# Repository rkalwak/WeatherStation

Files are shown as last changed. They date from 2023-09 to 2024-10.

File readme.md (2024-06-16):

# Stacja pogodowa

Poczytałem trochę co będzie potrzebne, kupiłem niekompletna stacje Sainlogic WS3500 na A****** i tak powstało to cudo :D

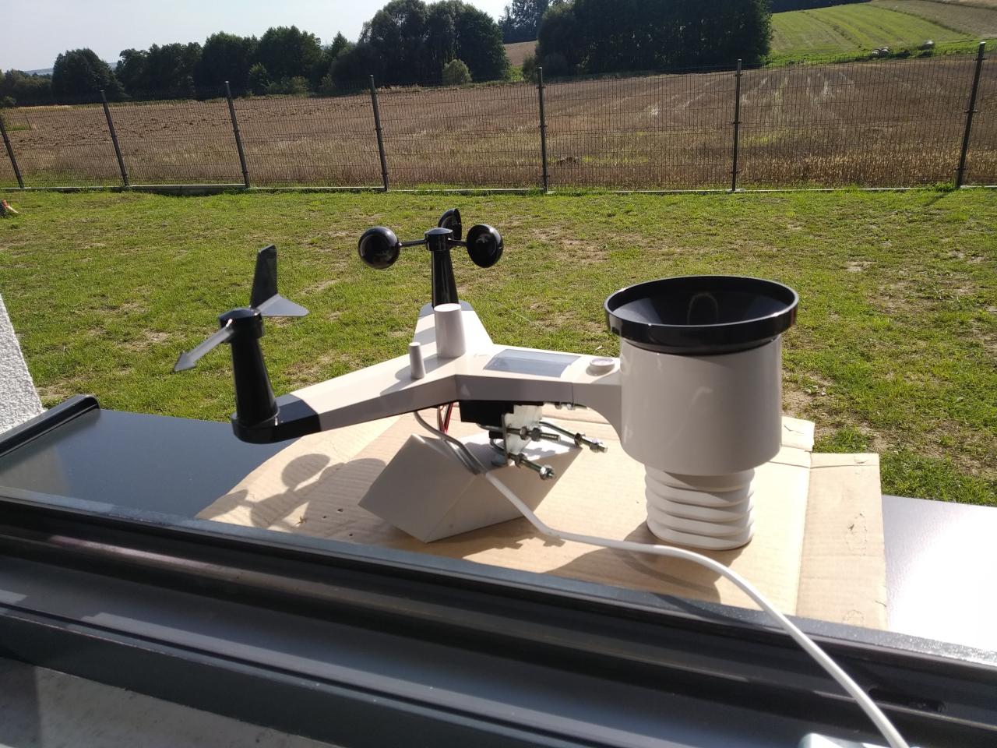
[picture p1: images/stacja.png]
stacja


## Funkcjonalności:
* 2x temperatura,
* wilgotność,
* ciśnienie atmosferyczne,
* siła i kierunek wiatru,
* ilość opadów,
* pył PM_0.5
* pył PM_1.0
* pył PM_2.5
* pył PM_4.0
* pył PM_10.0

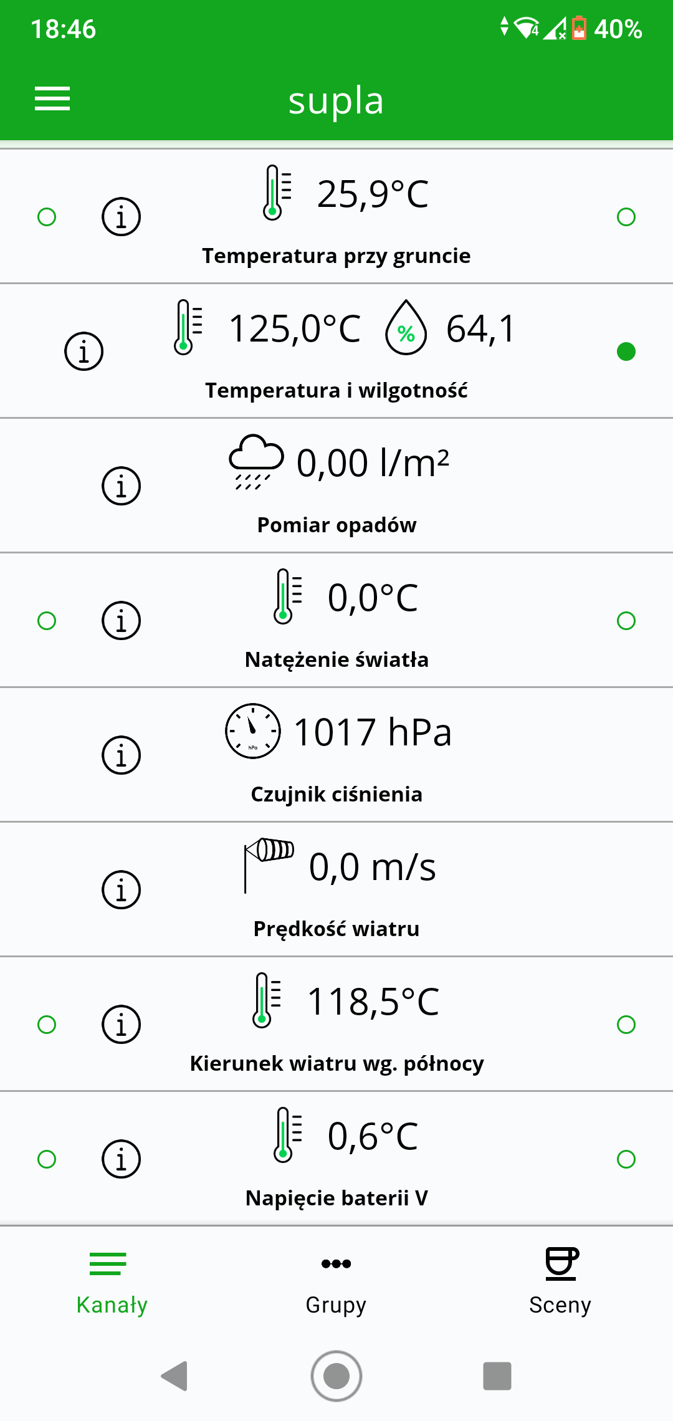
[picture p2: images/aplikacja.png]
aplikacja


## Części:
* niekompletna stacja Sainlogic WS3500 - bez tabletu i zasilacza -> nie można jej skonfigurować, ale nieuszkodzona, wyrwana za 100zł :D
* ESP32 DevKit
* HDC1080 - czujnik wilgotności i temperatury
* MS5611 - czujnik ciśnienia
* DS18B20 - czujnik temperatury przy gruncie
* LTR390 - czujnik UV i natężenia światła wbudowany w stację, użyty jako ten drugi
* AS5600 - enkoder magnetyczny, zastąpił czujnik kierunku wiatru w stacji
* czujnik Halla - zastąpil czujnik siły wiatru w stacji , ten od czujnika opadów został
* 2 baterie 18650 LiPo i koszyk
* lx-lifc1-n - Moduł BMS z ładowarką do akumulatorów Li-ion 2S z USB typu C i obsługą QC, możliwość ładowania z USB albo panelu.
* przetwornica step-down
* panel fotowoltaiczny dający 7V i ok. 1W wbudowany w stację
* Sensirion SPS30 - czujnik pyłu zawieszonego

## Schemat i sposób działania
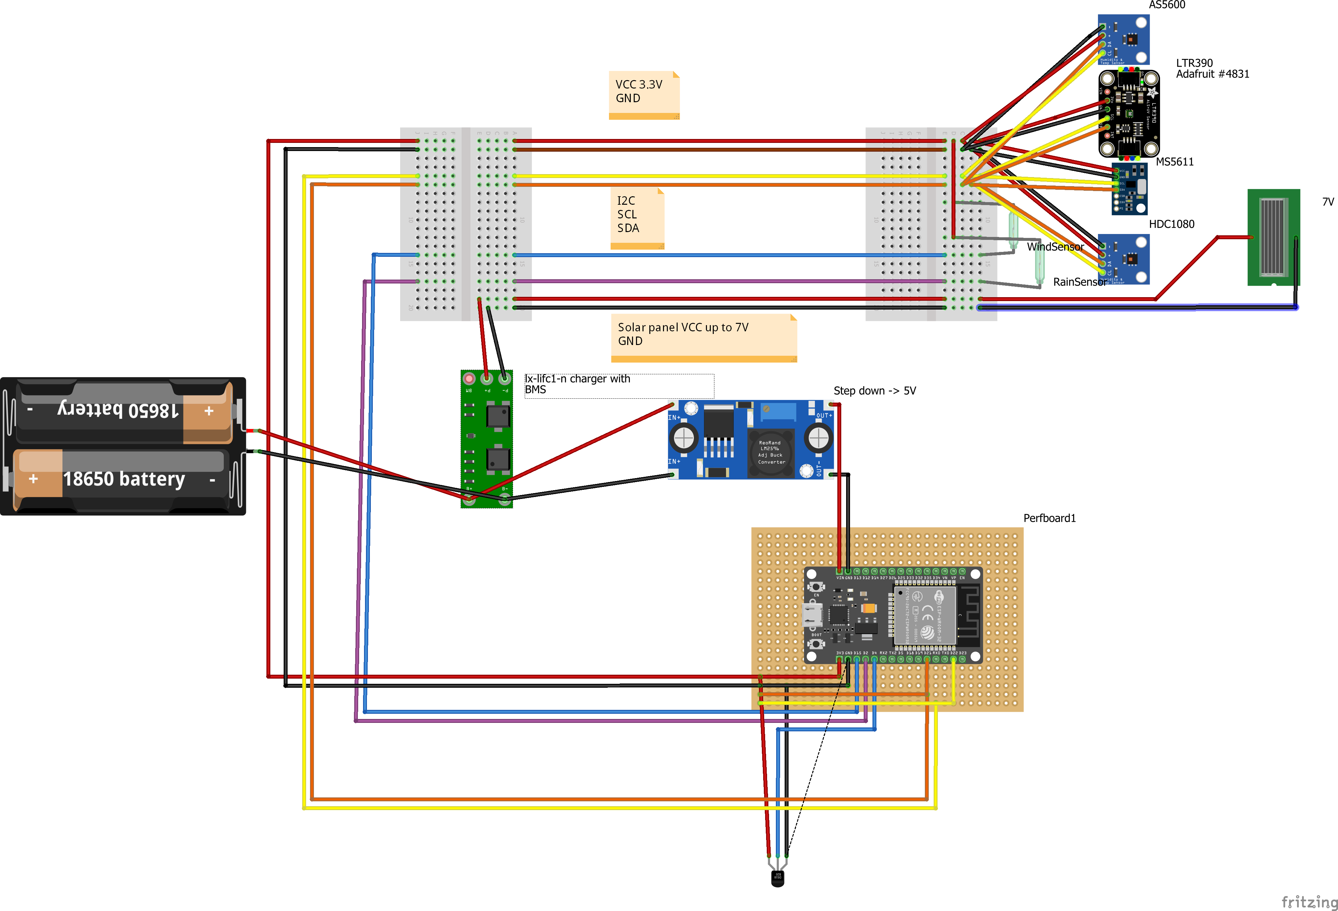
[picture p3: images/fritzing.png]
fritzing


ESP32 jest wyciągniete do zewnętrznej puszki wraz z zasilaniem, ze względu na rozmiar stacji, po prostu się w niej nie mieści. Użyłem 12 żyłowego, 2 metrowego przewodu telefonicznego do połaczenia płytki w stacji z tą w puszce.

Wykorzystałem panel fotowoltaiczny z kupionej stacji do ładowania akumulatorków, jednak jest za słaby aby w pełni naładować 2 akumulatorki i co najwyżej wydłuża czas pracy na bateriach, który bez panelu wynosi ponad dobę pracy non stop. Ostatecznie stacja jest podłączona do zasilacza 12V w garażu.

## Problemy

### Brak schematów do stacji Sainlogic WS3500 i opisów na płytkach

Metodą prób i błędów wymyśliłem jak wykorzystać niektóre wbudowane czujniki.

LTR390 po wyjęciu i zobaczeniu oznaczeń pinów podpiąłem do ESP i puściłem skaner I2C a potem po adresie znalazłem czujnik, po dobraniu biblioteki zadziałał :D 

Niestety ten sam manewr nie zadziałał z czujnikiem temperatury i wilgotności. Mimo, że wygląda jak AHT XX i ma właściwy adres I2C nie działa z żadną biblioteką do tych czujników.

Czujnik Halla dla opadów zadziałał. Doświadczalnie trzeba było dobrać jego pojemność.

Czujnik Halla dla siły wiatru najpierw działał a potem przestał... Kupiłem inny i działa, ale obserwując dane w Supli, muszę poprawić obliczanie prędkości wiatru.

Po kilku godzinach czytania okazało się, że kierunek wiatru jest zrealizowany przez dwa czujniki Halla i coś jeszcze, ale nie rozkminiłem tego... Kupiłem za to enkoder magnetyczny, który podaję kąt w stopniach - idealnie.

### Zasilanie

Pierwsza opcja: 1 akumulatorek 18650 i LDO na 3.3V, owszem ESP się uruchomi, ale z Wifi już się nie połączy przy obciążeniu wszystkimi czujnikami. Użyłem AMS1117 jako LDO. 

Druga opcja: 2 akumulatorki 18650 i przetwornica StepDown ustawiona na 5V, podane na VIN pin. Działa, ale chyba marnuje możliwości akumulatorków. Dodatkowo dwa akumulatorki to za dużo aby naładować z małego panela dającego max 7V, więc chyba skończy się to większym panelem :D

Trzecia opcja: zasilanie z USB - nie mam póki co dobrego miejsca, żeby stacja wisiała na rozsądnej i dostępnej wysokości i był bezpieczny i wygodny dostęp do prądu.

Czwarta opcja: czytałem, że ESP32 DevKit może przyjąć do 12V na VIN pin, podłączył bym bezpośrednio baterie, ale jakoś się nie odważyłem jeszcze, ktoś próbował?

Stanęło na zasilaczu 12V.

### Dokładność pomiarów

ADC w ESP32 jest trochę słabe, pomiar napięcia akumulatorków jest "mniej więcej", wahania rzędu 0.3V.

HDC1080 się bardzo grzeje w obudowie radiacyjnej i generalnie w południe pokazuje głupoty w stosunku do DS18B20 wiszącego luźno w cieniu, aczkolwiek wilgotność pokazuje nieźle co jest dziwne. Więc muszę to przemyśleć.

Siła wiatru zdecydowanie będzie lepiej oprogramowana bo nie znając możliwości wiatraczka błądzę w obliczeniach.

### Supla i jej możliwości

Niektóre pomiary musiały zostać przepchnięte przez kanał temperatury, np. kierunek wiatru jako kąt z zakresu 0-360 względem północy.

## Plany na przyszłość

- brak

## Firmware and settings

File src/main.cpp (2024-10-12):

#include <Arduino.h>
#define normalMode 1
#include <SuplaDevice.h>
#include <supla/sensor/DS18B20.h>
#include <Wire.h>
#include <HDC1080.h>
#include <MS5611Sensor.h>
#include <supla/sensor/rain.h>
#include <supla/sensor/wind.h>
#include <supla/sensor/pressure.h>
#include <supla/channel_element.h>
#include <supla/network/esp_wifi.h>
#include <LightSensor.h>
#include <RainSensor.h>
#include <supla/clock/clock.h>
#include <Anemometr.h>
#include <WindDirection.h>
#include <SPS30Sensor.h>
#include <VoltageSensor.h>
#include <supla/storage/littlefs_config.h>
#include <supla/network/esp_web_server.h>
#include <supla/network/html/device_info.h>
#include <supla/network/html/wifi_parameters.h>
#include <supla/network/html/protocol_parameters.h>
#include <supla/device/supla_ca_cert.h>

Supla::Clock suplaClock;
Supla::Sensor::RainSensor *rainSensor;
bool resetOncePerHour = true;

Supla::ESPWifi wifi(wifiSSID, wifiPass);
Supla::LittleFsConfig configSupla;
long lastRead=0;

void setup()
{

  Serial.begin(115200);
  // Replace the falowing GUID with value that you can retrieve from https://www.supla.org/arduino/get-guid
  char GUID[SUPLA_GUID_SIZE] = {0x59, 0x37, 0xA9, 0x23, 0x69, 0x7E, 0x90, 0xD3, 0x48, 0x2A, 0x30, 0xC7, 0xA7, 0x96, 0xAF, 0x46};

  // Replace the following AUTHKEY with value that you can retrieve from: https://www.supla.org/arduino/get-authkey
  char AUTHKEY[SUPLA_AUTHKEY_SIZE] = {0xF9, 0x39, 0x9D, 0x7E, 0x4E, 0xE6, 0x6B, 0x92, 0x1E, 0x18, 0xBD, 0x9A, 0x39, 0xB2, 0xB2, 0x0E};
 
 Supla::Storage::Init();

  auto cfg = Supla::Storage::ConfigInstance();

  if (cfg)
  {
    char buf[100];
    if (!cfg->getGUID(buf))
    {
      Serial.println("[Main] setting config.");
      cfg->setGUID(GUID);
      cfg->setAuthKey(AUTHKEY);
      cfg->setWiFiSSID(wifiSSID);
      cfg->setWiFiPassword(wifiPass);
      cfg->setSuplaServer(serverVariable);
      cfg->setEmail(emailVariable);
    }
    else
    {
      Serial.println("[Main] Can load guid.");
    }
  }
  else
  {
    Serial.println("[Main] Config not found.");
  }
  new Supla::Sensor::LightSensor();
  Supla::Sensor::SPS30_X *sps30 = new Supla::Sensor::SPS30_X();
  auto spsPM005 = new Supla::Sensor::SPS30_PM005(sps30);
  auto spsPM01 = new Supla::Sensor::SPS30_PM01(sps30);
  auto spsPM025 = new Supla::Sensor::SPS30_PM025(sps30);
  auto spsPM04 = new Supla::Sensor::SPS30_PM04(sps30);
  auto spsPM10 = new Supla::Sensor::SPS30_PM10(sps30);
  
  uint8_t internalTemp[8] = { 0x28, 0x52, 0x29, 0xB5, 0x63, 0x20, 0x01, 0x9B }; // wewnatrz garazu
  uint8_t externalTemp[8] = { 0x28, 0x1C, 0x7F, 0x57, 0x04, 0xE1, 0x3C, 0x56 }; // na zewnatrz
  auto ds= new Supla::Sensor::DS18B20(4, internalTemp);
  new Supla::Sensor::HDC1080();  
  new Supla::Sensor::MS5611Sensor(248);
  rainSensor = new Supla::Sensor::RainSensor(2, 2.5, 300);
  new Supla::Sensor::WindDirectionSensor(18, 15);

  new Supla::Sensor::Anemometr(15, 1, 0);
  auto ds2= new Supla::Sensor::DS18B20(4, externalTemp);
  // new Supla::Sensor::VoltageMeasurement(34);
  
  Wire.setClock(100000);
  
  SuplaDevice.setSuplaCACert(suplaCACert);
  SuplaDevice.setSupla3rdPartyCACert(supla3rdCACert);
  SuplaDevice.begin();
  SuplaDevice.addClock(new Supla::Clock);
  Serial.print("RRSI: ");
  Serial.println(WiFi.RSSI());
}

void loop()
{
  SuplaDevice.iterate();
  // reset counter every hour as rain is counter hourly
  if (suplaClock.getMin() == 0 && resetOncePerHour)
  {
    rainSensor->setReset(true);
    resetOncePerHour = false;
  }
  if (suplaClock.getMin() == 1)
  {
    resetOncePerHour = true;
  }

  if(millis()- lastRead > 10000)
  {
    Serial.print("RRSI: ");
    Serial.println(WiFi.RSSI());
    lastRead=millis();
  }
}

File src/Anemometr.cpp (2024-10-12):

/*
 This program is free software; you can redistribute it and/or
 modify it under the terms of the GNU General Public License
 as published by the Free Software Foundation; either version 2
 of the License, or (at your option) any later version.
 This program is distributed in the hope that it will be useful,
 but WITHOUT ANY WARRANTY; without even the implied warranty of
 MERCHANTABILITY or FITNESS FOR A PARTICULAR PURPOSE.  See the
 GNU General Public License for more details.
 You should have received a copy of the GNU General Public License
 along with this program; if not, write to the Free Software
 Foundation, Inc., 59 Temple Place - Suite 330, Boston, MA  02111-1307, USA.
*/

#include <Time.h>
#include "Anemometr.h"
#include <Arduino.h>
namespace Supla
{
  namespace Sensor
  {

    unsigned long lastWindTime;
    unsigned long stopSampling = 0;
    long Anemometr::_currentWindCount = 0;
    unsigned long Anemometr::_shortestWindTime = 0;

    void ICACHE_RAM_ATTR serviceInterruptAnem()
    {
      unsigned long currentTime = (unsigned long)(micros() - lastWindTime);

      lastWindTime = micros();
      if (currentTime > 1000) // debounce
      {
        Anemometr::_currentWindCount++;
        if (currentTime < Anemometr::_shortestWindTime)
        {
          Anemometr::_shortestWindTime = currentTime;
        }
      }
    }

    Anemometr::Anemometr(int pinAnem, double wind_factory, int selectedMode) : lastReadTime(0) // constructor
    {

      channel.setType(SUPLA_CHANNELTYPE_WINDSENSOR);
      channel.setDefault(SUPLA_CHANNELFNC_WINDSENSOR);
      channel.setNewValue(WIND_NOT_AVAILABLE);

      _pinAnem = pinAnem;
      _wind_factory = wind_factory;
      _currentWindCount = 0;
      _currentWindSpeed = 0.0;

      lastWindTime = 0;
      _shortestWindTime = 0xffffffff;

      _sampleTime = 5.0;
      _startSampleTime = micros();
    };

    double Anemometr::getValue() // in milliseconds
    {
#ifdef normalMode
      _currentWindSpeed = get_current_wind_speed_when_sampling();
      /*
      if (!_selectedMode)
      {
        _currentWindSpeed = get_current_wind_speed_when_sampling();
      }
      else
      {

        startWindSample(SAMPLETIME);
        _currentWindCount = 0;
        if(stopSampling > _sampleTime * 1000)
        {
          _currentWindSpeed = ((float)_currentWindCount / _sampleTime) * _wind_factory;
        }
        delay(_sampleTime * 1000);

      }
      */
      return _currentWindSpeed;
#else
      return 0.0;
#endif
    };

    void Anemometr::iterateAlways()
    {
      if (millis() - lastReadTime > 10000)
      {
        lastReadTime = millis();
        channel.setNewValue(getValue());
        Serial.print("Speed: ");
        Serial.println(getValue());
      }
    }

    float Anemometr::get_wind_gust()
    {
      unsigned long latestTime;
      latestTime = _shortestWindTime;
      _shortestWindTime = 0xffffffff;
      double time = latestTime / 1000000.0; // in microseconds

      return (1 / (time)) * _wind_factory / 2;
    };

    void Anemometr::reset_wind_gust()
    {
      _shortestWindTime = 0xffffffff;
    };

    void Anemometr::startWindSample(float sampleTime)
    {

      _startSampleTime = micros();

      _sampleTime = sampleTime;
    };

    float Anemometr::get_current_wind_speed_when_sampling()
    {

      unsigned long compareValue;
      compareValue = _sampleTime * 1000000;

      if (micros() - _startSampleTime >= compareValue)
      {
        // sample time exceeded, calculate currentWindSpeed
        float _timeSpan;
        //     _timeSpan = (unsigned long)(micros() - _startSampleTime);
        _timeSpan = (micros() - _startSampleTime);

        _currentWindSpeed = ((float)_currentWindCount / (_timeSpan)) * _wind_factory * 1000000;

        _currentWindCount = 0;

        _startSampleTime = micros();
      }
      else
      {
        // Serial.println("NOT Triggered");
        // Serial.print("time = ");
        // Serial.println(micros() - _startSampleTime);
        //  if not, then return last wind speed
      }
      return _currentWindSpeed;
    };

    void Anemometr::onInit()
    {

      pinMode(_pinAnem, INPUT_PULLUP);
      digitalWrite(_pinAnem, HIGH);
#ifdef normalMode
      attachInterrupt(digitalPinToInterrupt(_pinAnem), serviceInterruptAnem, FALLING);
#endif
      channel.setNewValue(getValue());
    }

  }; // namespace Sensor
}; // namespace Supla
